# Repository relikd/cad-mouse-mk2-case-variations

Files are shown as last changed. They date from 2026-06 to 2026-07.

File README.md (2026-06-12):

CAD Mouse MK2 - Case Variations
===============================

Based on the 3D files from <https://github.com/sb-ocr/cad-mouse-mk2> (CC-BY-NC-SA-4.0) ... THANK YOU for this project.

The 3D model files in this repo have been recreated from scratch, in [FreeCAD](https://github.com/FreeCAD/FreeCAD/).
The original model sticks to the original step files as closely as possible.

The purpose of this repo is to collect user variations on the original design.

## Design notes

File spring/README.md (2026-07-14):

Spring Designs
==============

All springs come with a default height of 4mm.
If you want a thinner spring, use your slicer to cut down the height (use the scaling feature and click the padlock to scale height independent of width and length).

All designs come with variants for:
- Stem type (`original`/`OG` three screws, `single-center-screw`/`SCS` triangle hole)
- Stem hole orientation (`CF`: flipped for `magnet-holder-v2`, `CN` original orientation `magnet-holder-original`)

See [Tips for experimenting](#tips-for-experimenting) at the end of this readme.

## Spacer

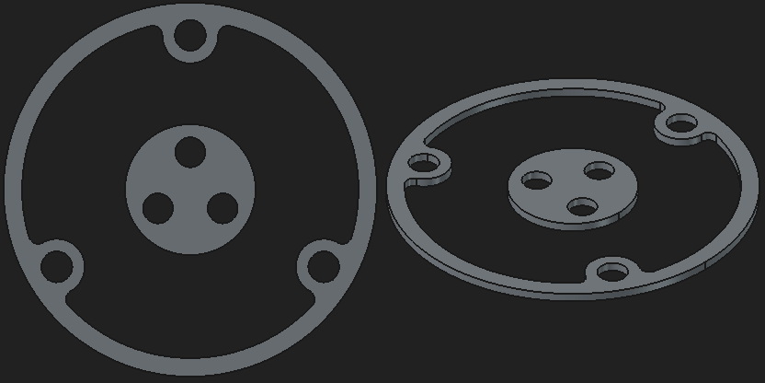
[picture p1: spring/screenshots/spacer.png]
spacer


If you use a thinner spring, you must match the height with a spacer.
`spring` + `spacer` = 4mm.

## Original

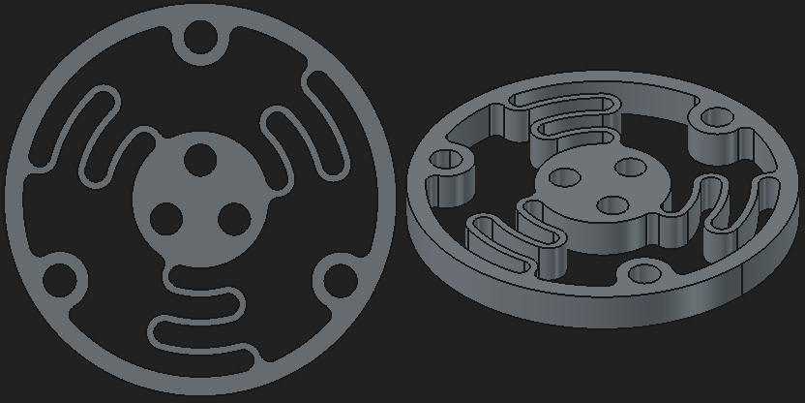
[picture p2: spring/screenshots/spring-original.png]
original


The original spring design by [Salim Benbouziyane](https://github.com/sb-ocr/cad-mouse-mk2).

## Stacked

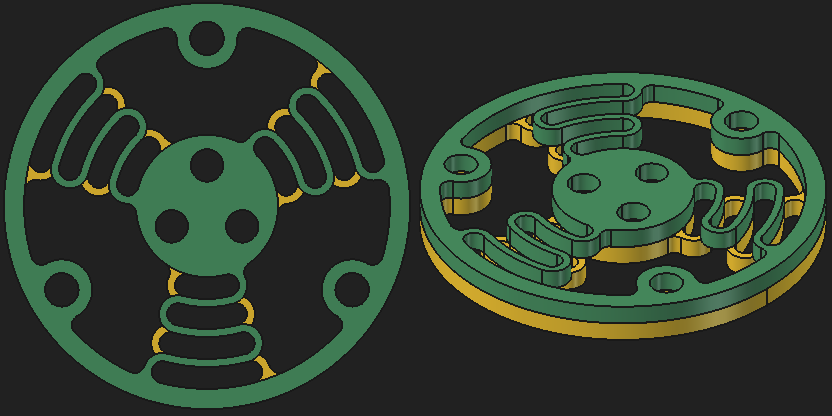
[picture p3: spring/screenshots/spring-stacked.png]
stacked


Print the original spring two times, with half the height (2x 2mm).
Mount them together, such that one side is flipped upside-down.

- Fixes rotation around Z-axis (both directions use the same force)
- Z-axis translation (pull up-/down) is softer (better with a lightweight base)

## Mirrored Double

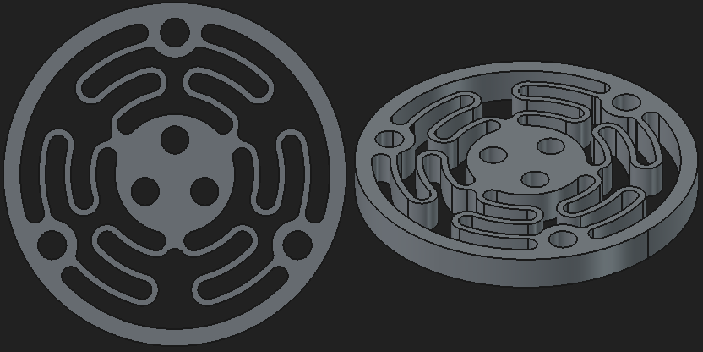
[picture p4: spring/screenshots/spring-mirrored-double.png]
mirrored-double


Same as the `Stacked` variant above but in a single design.
Careful with the height: because this variant uses twice the amount of springs, a 2mm spring will be nearly as stiff as the 4mm `Original` spring.

## Seventeen

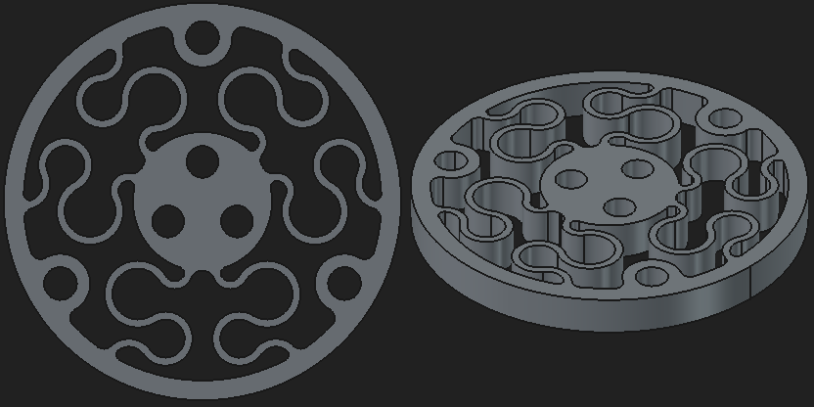
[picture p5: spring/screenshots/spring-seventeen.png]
seventeen


Translation in XY is still not perfect but it strikes a good balance in all DoF.
A height of 2.5mm seems best so far.

The design batch which led to most of the insights in [Tips for experimenting](#tips-for-experimenting).
(large arcs near center, outer ring anchor points at 60° intervals, XY movements, etc.).

See the `attempts/batch-1` folder how miniscule the changes are (v11 - v18).

## Tips for experimenting

- Spring height determines stiffness of the Z-axis.
  For example, with a 2mm spring, the up-/down motion is much easier.
  But on the other hand, tilting also becomes easier.
  E.g., translation on the X- and Y-axis becomes harder because each push may inadvertently rotate the scene.
  It is also a bit harder to rotate around the Z-axis in a steady motion.
- Thinner spring walls increase sensitivity in the X- and Y-axis.
  If you want to go below the 0.8mm in the original design, you'd need a finer nozzle (<0.4mm).
  (unless you are ok with just a single filament line).
- The hardest part, is to find a design which maps 3 springs on a 2-dimensional translation.
  All four XY directions should require the same amount of pressure (or at least: the two opposite directions should require the same force).
  E.g., pulling down on the "bottom" spring should compress equally as the other two springs pushing left- or right.
- If you go for a 6-spring design, try to place the outer-ring anchor points in 60° increments.
  This way, the spring is balanced equally in all four directions.
- Pay attention to spring direction.
  If all springs point in the same direction (like in the original design), rotation around the Z-axis will be easier in one direction than the other.
- The spring is deformed more at the center than at the edges.
  Therefore the center part should be the most flexible (larger arcs).
- When you find a good design, try the extremes.
  Rotate into corners where the spring may collide onto itself or onto the `Knob`.
  Add extra clearance to avoid rasping.
- Always try with the software in a test-scene.
  I had countless spring designs which felt good in a dry run (just the hardware haptics) but did not match my expectations when used in real software.

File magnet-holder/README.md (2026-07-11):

Magnets Holder
==============

## Original

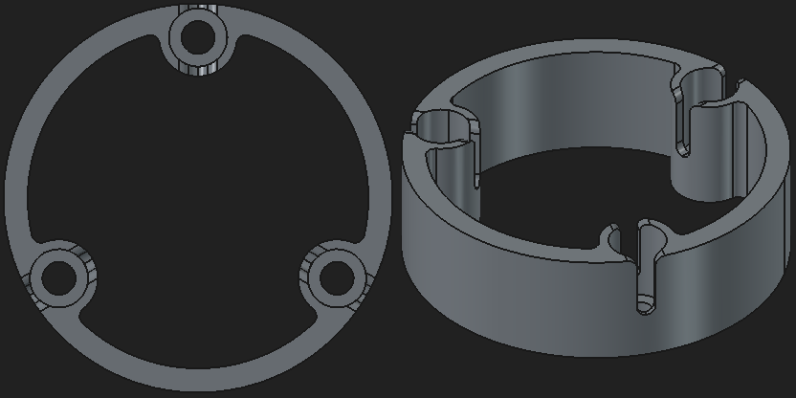
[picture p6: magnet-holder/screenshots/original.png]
original design


=> requires a spring with `_CN_` in name.

## Magnets Holder v2

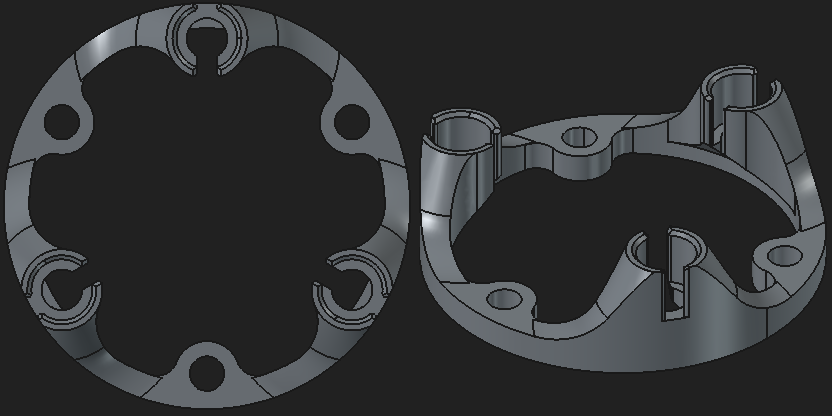
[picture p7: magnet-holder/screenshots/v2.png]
magnets holder v2


=> requires a spring with `_CF_` in name.

Main benefits:
- easier spring changes (unscrew without having to remove the magnets)
- easier magnets dis-/assembly (unscrew first, then handle magnets)
- easy to replace your existing `magnets-holder`

To replace your existing `magnets-holder`, you only need a new `spring`.
In the original spring, the center holes are pointing in the same direction as the holes on the outside ring.
For this `magnets-holder-v2`, they need to point in the opposite direction:

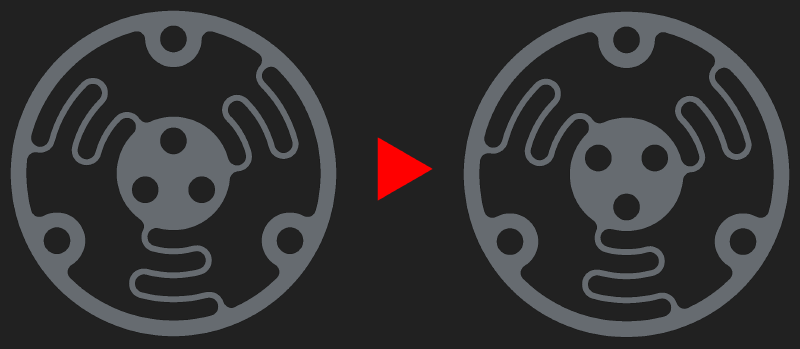
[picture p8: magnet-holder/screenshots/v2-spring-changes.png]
spring changes for v2


__Note:__ The magnets require a press-fit.
If they fall out, adjust the magnets-diameter variable.

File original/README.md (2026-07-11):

License: CC-BY-NC-SA 4.0

The FreeCAD and STL files in this folder were created by relikd.

The files in the STEP folder were extracted - without modification - from the original design.

Original design by [Salim Benbouziyane](https://github.com/sb-ocr/cad-mouse-mk2).

### Improvements

- fix counterbore overhangs with bridging (`Bottom Shell`, `Bottom Lid`).
- replace overhang fillets (z-axis) with 45° chamfers (`Knob`, `Bottom Shell`, `Bottom Lid`, `Button`).

#### Additional parts

- `magnet-holder`
- `spring`

### Notes

`base-shell-top` is the only part which needs supports.
For aesthetic reasons, the part should be printed in the final orientation such that it has a smooth top curvature.
You *could* print it upside-down (without support) but that will create a hard edge on the top (visible part).

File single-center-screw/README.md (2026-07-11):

Author: relikd

Based on: `original` + `print-improvements`

---

Re-designed to assemble all parts with a single center screw (M5) while maximizing bottom volume for weights.

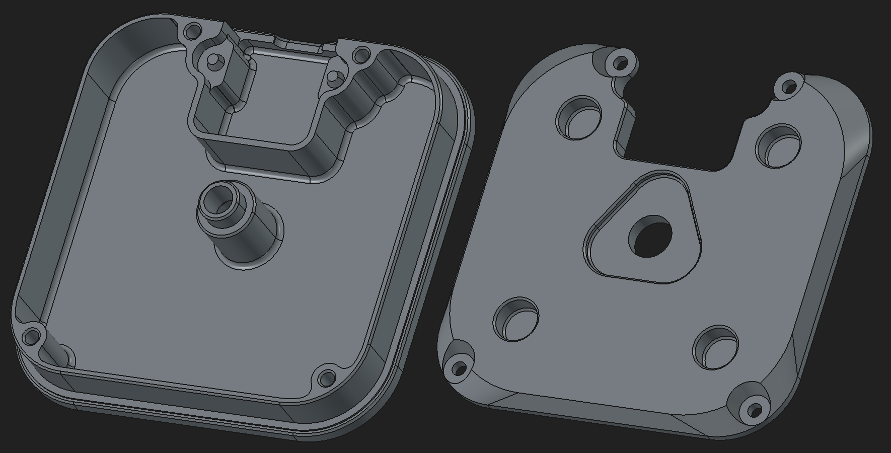
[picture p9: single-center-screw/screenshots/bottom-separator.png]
bottom and separator

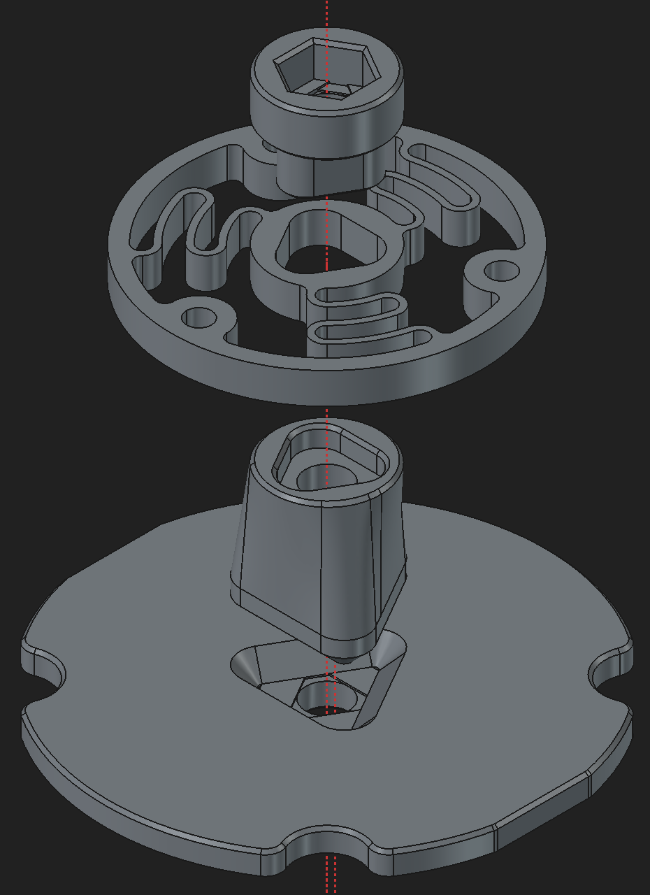
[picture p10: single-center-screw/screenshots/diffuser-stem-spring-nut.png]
stacked parts: diffuser, stem, spring, nut-cage


### Changes

- All heights are calculated from sensors board + MCU dimensions.
  This assures a minimal possible height and allows customizations for custom PCB designs.
- The `Top` and `Bottom` are fixed with self-tapping screws (no heat-set inserts needed, just regular 3mm).
- The model files `Top`, `Button`, and `Diffuser` have variant options (screw type and PCB variants (see below).
  All models have `VarSet` variables.

#### PCB variants

- Original (PCB design by [sb-ocr](https://github.com/sb-ocr/cad-mouse-mk2), the original release)
- Nikki (PCB design by [sheffieldnikki](https://github.com/sb-ocr/cad-mouse-mk2/issues/24), community variant, mounting the MCU directly onto the sensors board)

#### Additional parts

- `Knob` (from `original`)
- `magnet-holder`
- `spring`

### Print settings

- The model is tweaked for a minimum layer height of 0.2mm.
  Try not to go above or else you will have overhangs in screw holes etc. (or: adjust the printer variables in the model files)
- Only `Top` needs supports.
  All other parts have bridges for overhangs and should print without supports.

### Steel plate weight

Use `template-bottom-weight.dxf`, if you want to cut the weights from a steel plate.
The maximum possible height is 12.2mm - you can cut 3x 4mm plates or 2x 5mm.

### Bill of materials

I've included a range of possible screw lengths, just so you can re-use some scrap screws laying around.

- 6x Magnets 6mm x 3mm (same as original)
- 1x M5 x 40, Hexagon Socket Head Cap Screw
- 1x M5 nut
- 3x M3 x 10-12mm (`Knob`)
- 3x M3 Heat-Set Inserts 4mm (`Knob`)
- 4x M3 x 5-12mm (or Self-Tapping screws), sink head or another flat head with a low profile (<2mm)
  (connects `Separator` to `Bottom` and *may* collide with `Top` if head sticks out too much)
- 4x M3 x 4-7mm  (or Self-Tapping screws), any flat head type will do (connects PCB to `Top`)

Self-tapping screws are fine, because you won't need to open these parts very often (if ever).
Even if you do, a few screwing - unscrewing cycles should be fine.

Instead of self-tapping screws, you can use M3 screws *without* heat-set inserts, they will hold fine as well.
I still recommend heat-set inserts for the `Knob` as you might need to replace the `Spring` regularly.

If you use heat-sets for the top, you should adapt your hole size variable (e.g., 4.4mm).

### Assembly

The mouse consists of three main parts: bottom, top, and knob.

1. Fill the `Bottom` with weights (e.g., steel balls), fill it up with wax and then close it off with the `Separator`.
2. Place the `Diffuser` in the `Top` shell (the diffuser cut-out should point in the same direction as the USB port).
   Place the PCB onto the diffuser (pinout in the same direction).
   Then, screw both together and insert the MCU.
3. Combine the `Stem`, `Spring`, and `Nut-Cage`.
   Place the M5 nut into the cage.
   Combine this stack with the `Magnet-Holder` and fix both into the `Knob`.
4. Finally, stack all three components loosely together and insert the M5 screw carefully.
   Don't push too hard, or the nut will fall out (and you'll have to disassamble the knob again).

The single M5 screw holds all parts together.
Most parts have a tight fit.
Especially the spring and stem should fit as perfect as possible (reduces rotational wobble).

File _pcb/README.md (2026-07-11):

PCB variants
============

- `original` PCB files for <https://github.com/sb-ocr/cad-mouse-mk2>
- `nikki` PCB variant by [sheffieldnikki](https://github.com/sheffieldnikki).
See <https://github.com/sb-ocr/cad-mouse-mk2/issues/24>

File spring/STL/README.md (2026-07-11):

`{VARIANT}_{FLIPPED}_{filename}.stl`

VARIANT:
- OG: `Original` (three center holes)
- SCS: `Single-Center-Screw` (triangle center hole)

FLIPPED:
- CN: `non-flipped` (original orientation. Center holes point to magnets. `magnet-holder-original`)
- CF: `flipped` (center hole upside-down. Holes point between magnets. `magnet-holder-v2`)

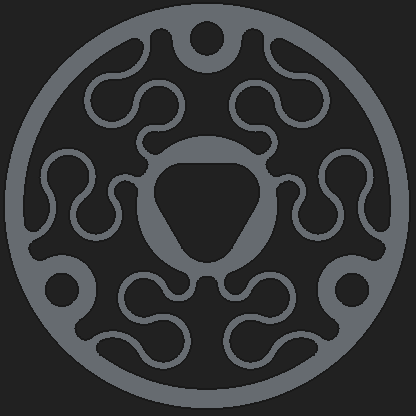
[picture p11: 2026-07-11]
spring/attempts/batch-1/v13.png

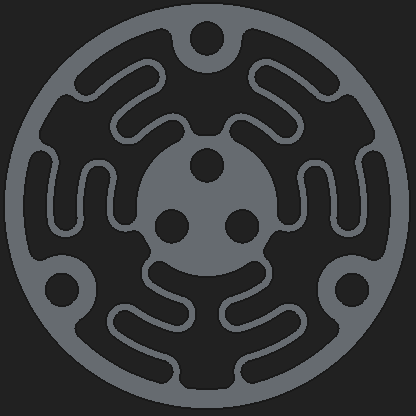
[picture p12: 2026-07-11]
spring/attempts/batch-1/v2.png

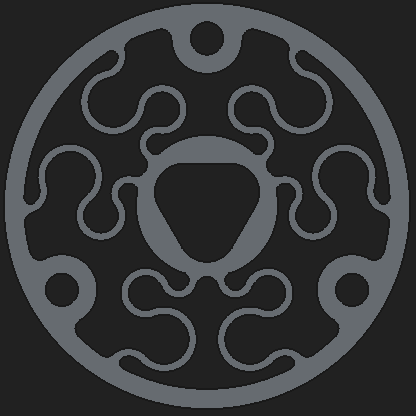
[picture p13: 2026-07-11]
spring/attempts/batch-1/v18.png

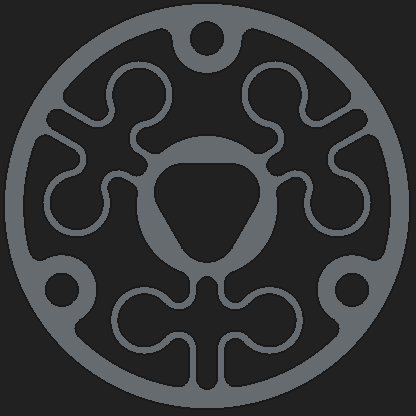
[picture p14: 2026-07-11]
spring/attempts/batch-1/v10.png

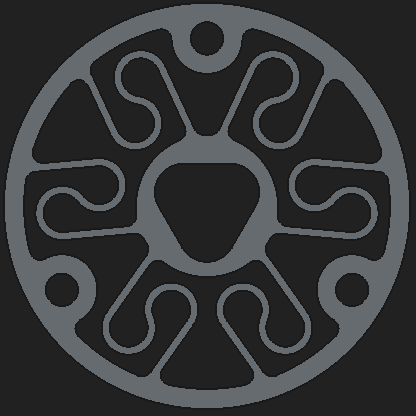
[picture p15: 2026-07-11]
spring/attempts/batch-1/v7.png

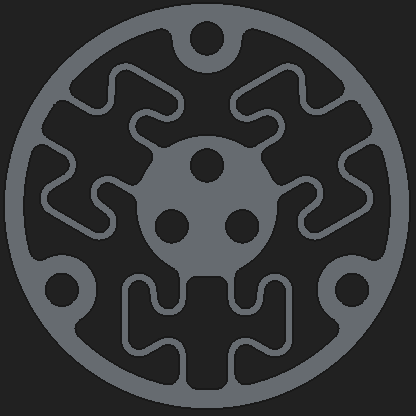
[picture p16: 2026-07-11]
spring/attempts/batch-1/v9.png

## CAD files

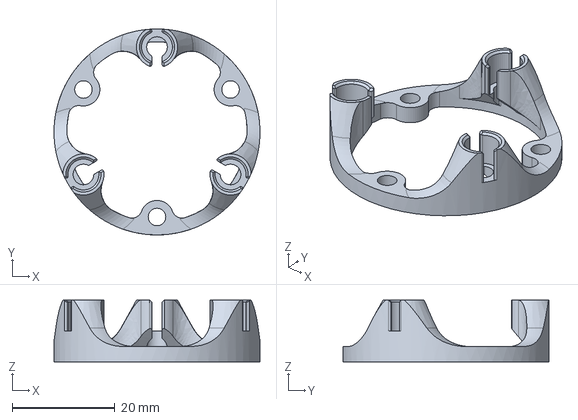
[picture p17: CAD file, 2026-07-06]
magnet-holder/magnet-holder-v2.FCStd
40.0 x 40.0 x 12.0 mm

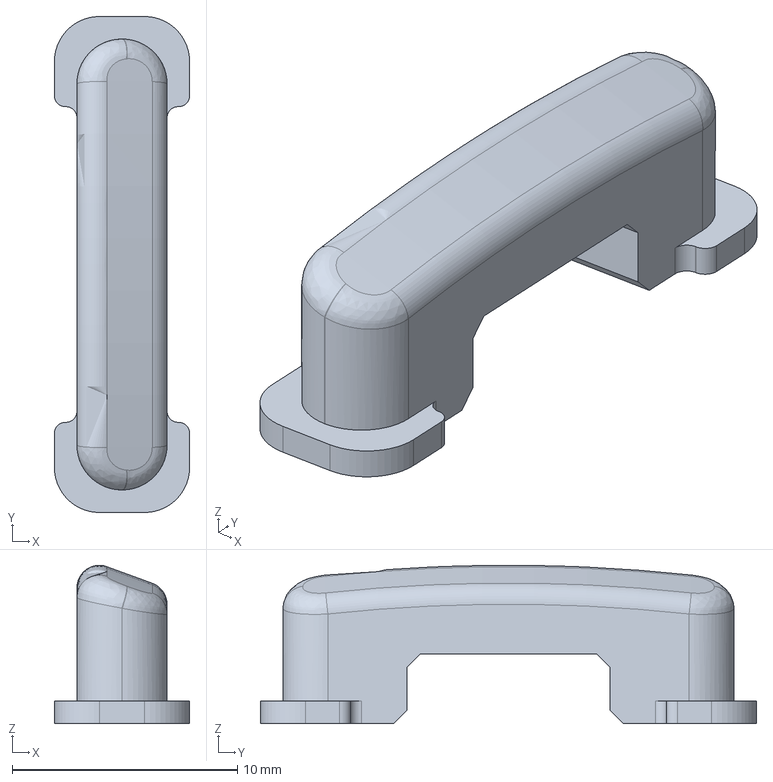
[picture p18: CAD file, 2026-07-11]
original/button.FCStd
6.00 x 22.0 x 7.03 mm

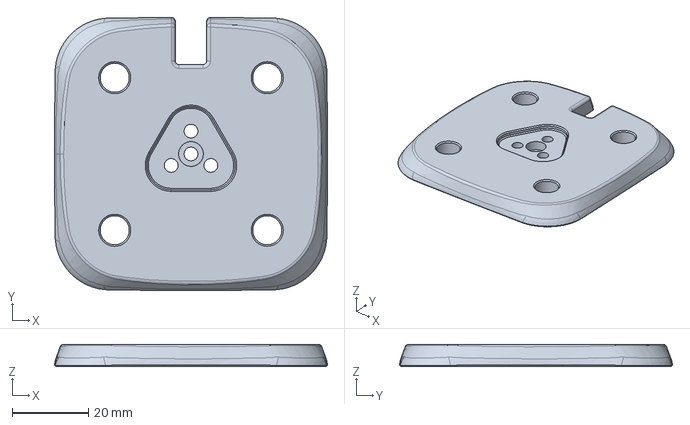
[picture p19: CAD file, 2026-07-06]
original/STEP/Base _Bottom Sep.step
71.6 x 71.6 x 5.90 mm

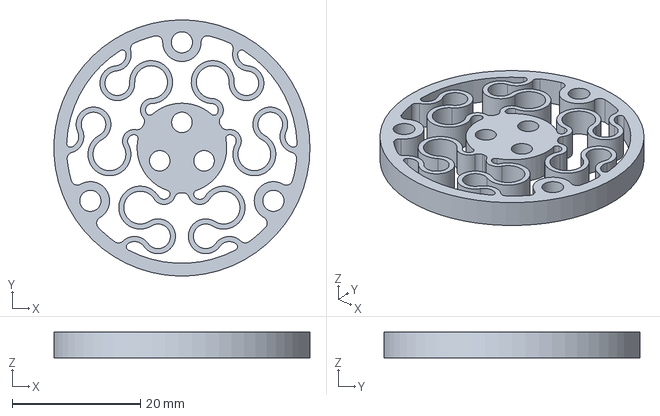
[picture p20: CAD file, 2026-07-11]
spring/spring-seventeen.FCStd
40.0 x 40.0 x 4.00 mm

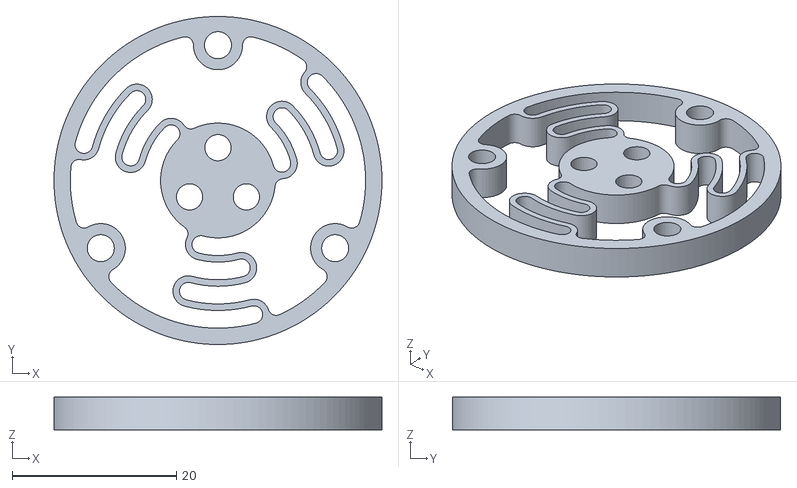
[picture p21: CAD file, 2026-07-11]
spring/STL/OG_CN_spring-original.stl
40.0 x 40.0 x 4.00

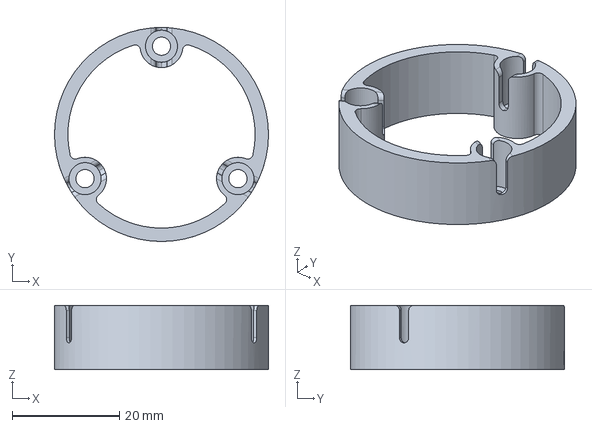
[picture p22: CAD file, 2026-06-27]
magnet-holder/magnet-holder-original.FCStd
40.0 x 40.0 x 12.0 mm

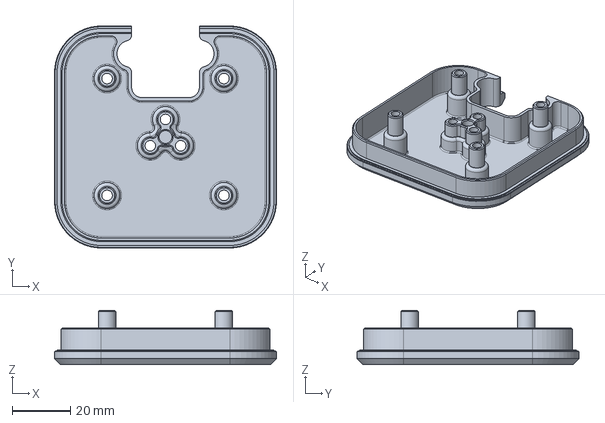
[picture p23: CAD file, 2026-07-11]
original/base-shell-bottom.FCStd
76.0 x 76.0 x 18.5 mm

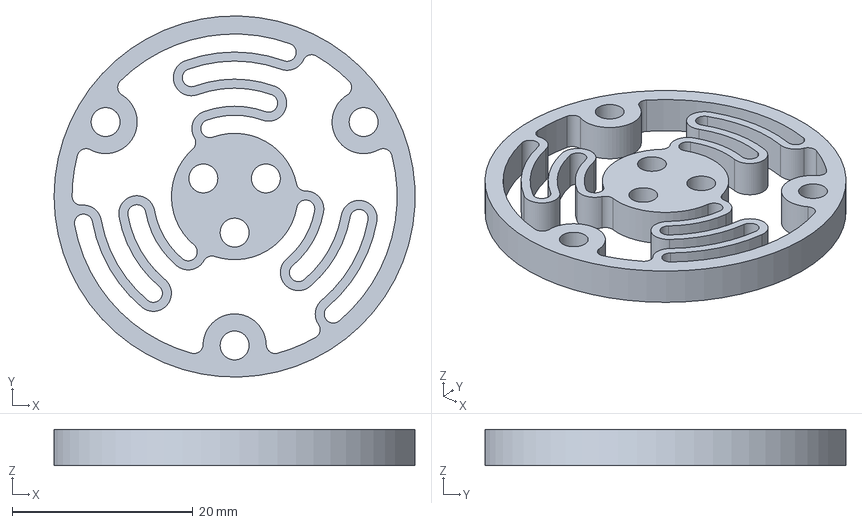
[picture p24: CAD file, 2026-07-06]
original/STEP/Spring v6.step
40.0 x 40.0 x 4.00 mm

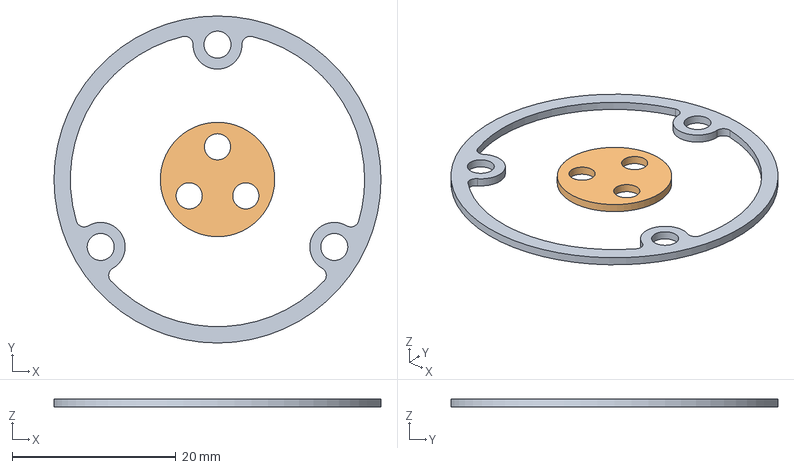
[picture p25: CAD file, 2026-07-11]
spring/spacer.FCStd
40.0 x 40.0 x 1.00 mm
Ring
Center

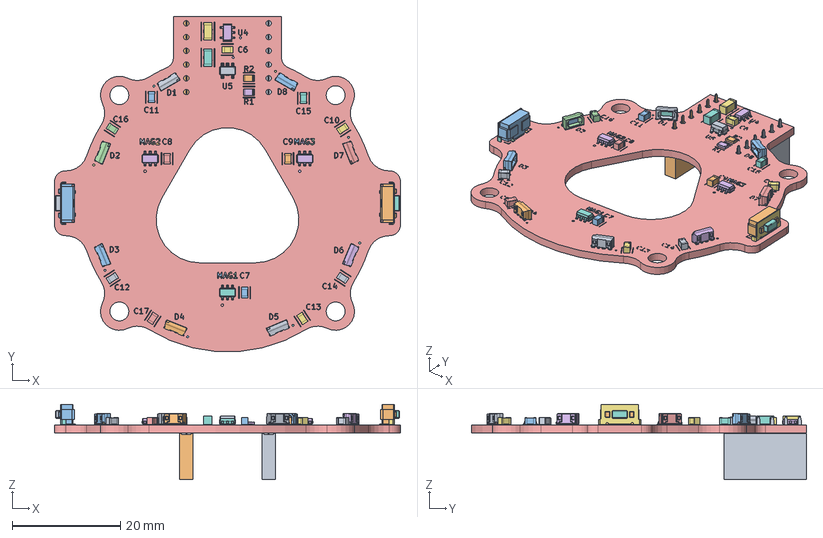
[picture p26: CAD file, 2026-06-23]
_pcb/nikki-sensorboard.FCStd
64.0 x 62.0 x 13.9 mm
SOT-23-5
SK6812 SIDE-A--3DModel-STEP-269445
SK6812 SIDE-A--3DModel-STEP-269446
SK6812 SIDE-A--3DModel-STEP-269447
SK6812 SIDE-A--3DModel-STEP-269448
SK6812 SIDE-A--3DModel-STEP-269449
SK6812 SIDE-A--3DModel-STEP-269450
SK6812 SIDE-A--3DModel-STEP-269452
SK6812 SIDE-A--3DModel-STEP-269453
SK6812 SIDE-A--3DModel-STEP-269454
SK6812 SIDE-A--3DModel-STEP-269455
SK6812 SIDE-A--3DModel-STEP-269456
SK6812 SIDE-A--3DModel-STEP-269457
TSOP-6_1.65x3.05mm_P0.95mm
C_0805_2012Metric
TS32-7-35-BK-B-160-RA-SMT-TR
TS32-7-35-BK-B-160-RA-SMT-TR001
TS32-7-35-BK-B-160-RA-SMT-TR002
TS32-7-35-BK-B-160-RA-SMT-TR003
TS32-7-35-BK-B-160-RA-SMT-TR004
SK6812 SIDE-A--3DModel-STEP-269459
SK6812 SIDE-A--3DModel-STEP-269460
SK6812 SIDE-A--3DModel-STEP-269461
SK6812 SIDE-A--3DModel-STEP-269462
SK6812 SIDE-A--3DModel-STEP-269463
SK6812 SIDE-A--3DModel-STEP-269464
SK6812 SIDE-A--3DModel-STEP-269466
SK6812 SIDE-A--3DModel-STEP-269467
SK6812 SIDE-A--3DModel-STEP-269468
SK6812 SIDE-A--3DModel-STEP-269469
SK6812 SIDE-A--3DModel-STEP-269470
SK6812 SIDE-A--3DModel-STEP-269471
C_0805_2012Metric001
R_0805_2012Metric
C_0805_2012Metric002
SK6812 SIDE-A--3DModel-STEP-269473
SK6812 SIDE-A--3DModel-STEP-269474
SK6812 SIDE-A--3DModel-STEP-269475
SK6812 SIDE-A--3DModel-STEP-269476
SK6812 SIDE-A--3DModel-STEP-269477
SK6812 SIDE-A--3DModel-STEP-269478
SK6812 SIDE-A--3DModel-STEP-269480
SK6812 SIDE-A--3DModel-STEP-269481
SK6812 SIDE-A--3DModel-STEP-269482
SK6812 SIDE-A--3DModel-STEP-269483
SK6812 SIDE-A--3DModel-STEP-269484
SK6812 SIDE-A--3DModel-STEP-269485
SK6812 SIDE-A--3DModel-STEP-269487
SK6812 SIDE-A--3DModel-STEP-269488
SK6812 SIDE-A--3DModel-STEP-269489
SK6812 SIDE-A--3DModel-STEP-269490
SK6812 SIDE-A--3DModel-STEP-269491
SK6812 SIDE-A--3DModel-STEP-269492
TSOP-6_1.65x3.05mm_P0.95mm001
TS32-7-35-BK-B-160-RA-SMT-TR006
TS32-7-35-BK-B-160-RA-SMT-TR007
TS32-7-35-BK-B-160-RA-SMT-TR008
TS32-7-35-BK-B-160-RA-SMT-TR009
TS32-7-35-BK-B-160-RA-SMT-TR010
C_0805_2012Metric003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

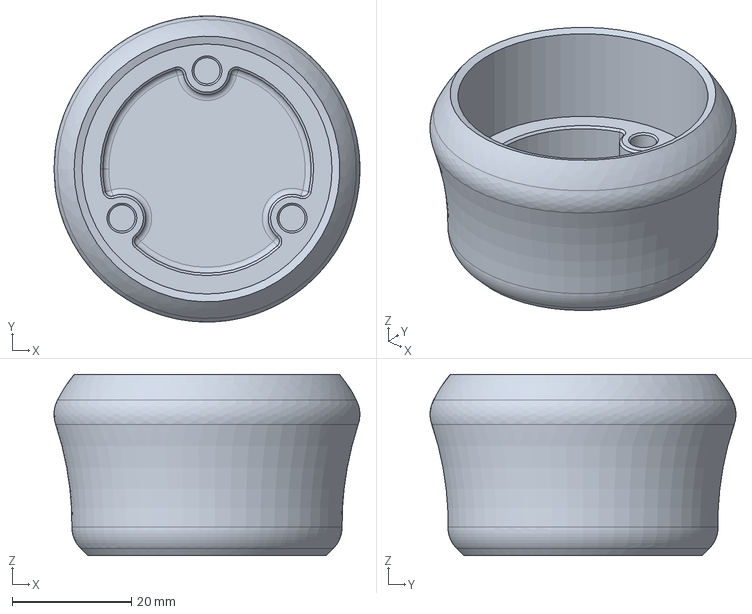
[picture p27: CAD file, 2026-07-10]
original/knob.FCStd
51.4 x 51.4 x 30.5 mm

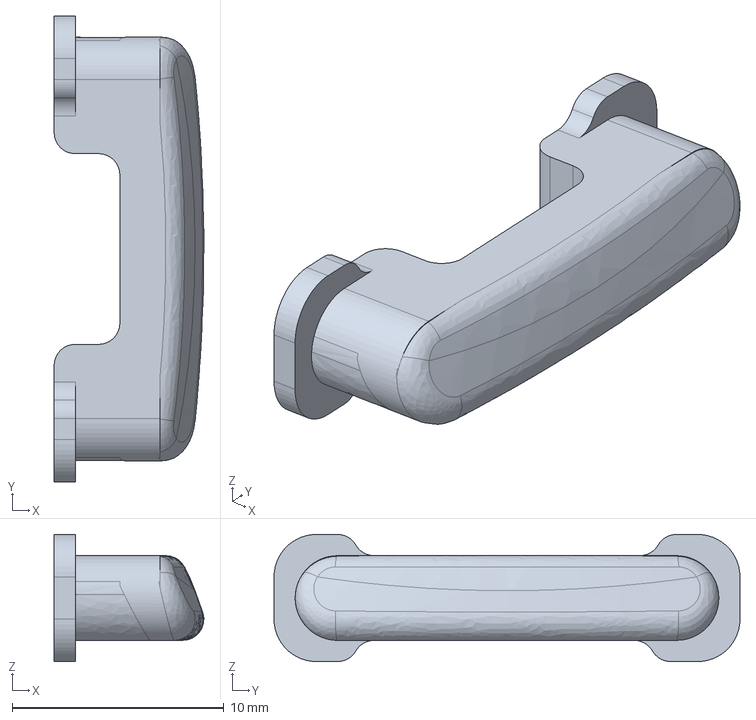
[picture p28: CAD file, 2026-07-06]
original/STEP/Buttons.step
7.07 x 22.0 x 6.00 mm

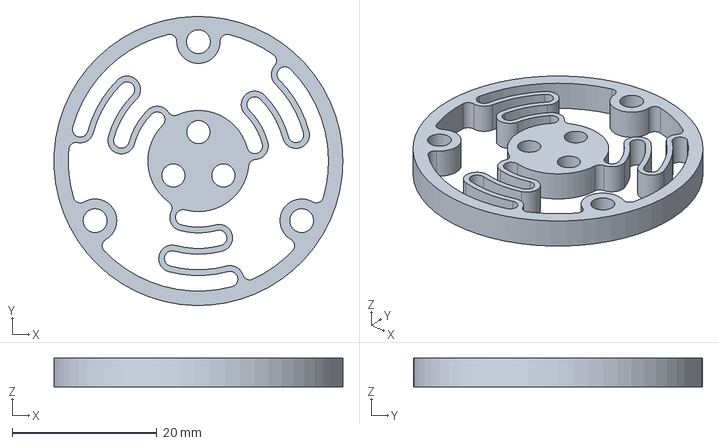
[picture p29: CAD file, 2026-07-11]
spring/spring-original.FCStd
40.0 x 40.0 x 4.00 mm

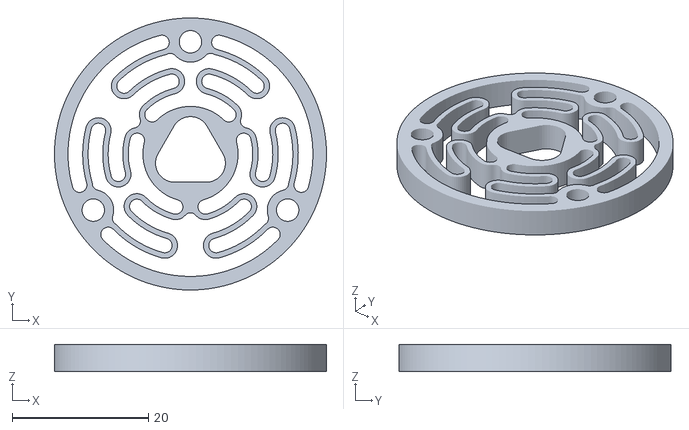
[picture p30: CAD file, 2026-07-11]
spring/STL/SCS_CN_spring-mirrored-double.stl
40.0 x 40.0 x 4.00

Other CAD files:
_pcb/original-assembly.FCStd
_pcb/nikki-assembly.FCStd
spring/STL/OG_CN_spacer.stl
_pcb/nikki-mcu.FCStd
_pcb/original-mcu.FCStd
_pcb/original-sensorboard.FCStd
magnet-holder/STL/magnet-holder-original.stl
magnet-holder/STL/magnet-holder-v2.stl
original/STEP/Base _Bottom Lid.step
original/STEP/Base _Bottom.step
original/STEP/Base _Top.step
original/STEP/Diffuser.step
original/STEP/Knob v11.step
original/STEP/Magnets Holder v11.step
original/STEP/Spring Spacer v4.step
original/STEP/Stem v9.step
original/STL/base-bottom-lid.stl
original/STL/base-separator.stl
original/STL/base-shell-bottom.stl
original/STL/base-shell-top.stl
original/STL/button.stl
original/STL/diffuser.stl
original/STL/knob.stl
original/STL/spring-spacer.stl
original/STL/stem.stl
original/base-bottom-lid.FCStd
original/base-separator.FCStd
original/base-shell-top.FCStd
original/diffuser.FCStd
original/spring-spacer.FCStd
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

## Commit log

2026-06-13 fix: assembly references + exploded view
    [assembly.FCStd]
2026-06-13 feat: add print-improvements
    [base-bottom-lid.FCStd, base-shell-bottom.FCStd, button.FCStd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]
2026-06-14 feat: stls + remove notch from knob + larger notch
    [base-bottom-lid.FCStd, base-bottom-lid.stl, base-shell-bottom.FCStd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]
2026-06-23 feat: STL for original
    [base-bottom-lid.stl, base-separator.stl, base-shell-bottom.stl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]
2026-06-23 ref: move PCBs into separate folder
    [assembly.FCStd, mcu.FCStd, sensorboard.FCStd]
2026-06-23 chore: move stl into STL folder
    [base-bottom-lid.stl, base-shell-bottom.stl, button.stl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]
2026-06-23 feat: pcb-nikki
    [assembly.FCStd, mcu.FCStd, sensorboard.FCStd]
2026-06-23 fix: heat-set inserts hole size 4.2mm
    [knob.FCStd, knob.stl]
2026-06-26 feat: single-center-screw
    [all.FCStd, bottom.FCStd, bottom.stl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]
2026-06-27 ref: make head-height an option variable
    [magnet-holder.FCStd]
2026-06-27 fix: hole size of separator independent of bottom
    [bottom.FCStd, separator.stl]
2026-06-27 ref: edit hole size variable directly without checkbox
    [top.FCStd]
2026-06-27 chore: update readme for single-center-screw
2026-06-29 feat: spring-mirrored-double
    [spring-double.FCStd]
2026-06-29 chore: stl files for spring-mirrored-double
    [spacer-original-0.5mm.stl, spacer-original-1.0mm.stl, spacer-original-1.5mm.stl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]
2026-07-03 feat: steel plate weight
    [bottom.FCStd, template-bottom-weight.dxf]
2026-07-05 fix: chamfer on button + fix STL artifacts
    [button-nikki.stl, button-original.stl, button.FCStd]
2026-07-05 fix: button placement (wrong calculation)
    [top-nikki-with-heatset.stl, top-nikki-without-heatset.stl, top-original-with-heatset.stl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]
2026-07-06 feat: original step files separated
    [Base _Bottom Lid.step, Base _Bottom Sep.step, Base _Bottom.step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]
2026-07-06 feat: magnets holder v2
    [magnet-holder-v2.FCStd, magnet-holder-v2.stl, spring-double.FCStd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]
2026-07-10 fix: button rim distance + remove top inner fillet
    [spring-2mm.stl, spring.stl, top-nikki-with-heatset.stl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]
2026-07-10 fix: heat-set insert hole size 4.4mm
    [knob.FCStd, knob.stl]
2026-07-11 ref: consolidate all springs into single folder
    [OG_CF_spacer.stl, OG_CF_spring-mirrored-double.stl, OG_CF_spring-original.stl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]
2026-07-11 feat: spring v17
    [OG_CF_spring-seventeen.stl, OG_CN_spring-seventeen.stl, SCS_CF_spring-seventeen.stl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]
2026-07-11 chore: rm export script, creates too large files
    [OG_CF_spacer.stl, OG_CF_spring-mirrored-double.stl, OG_CF_spring-original.stl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]
2026-07-11 ref: merge print improvements into original design
    [base-bottom-lid.FCStd, base-bottom-lid.stl, base-shell-bottom.FCStd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]
2026-07-11 chore: rm assembly, always breaks on edits
    [all.FCStd, assembly.FCStd, top-button.FCStd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]
2026-07-11 chore: consolidate PCB designs into single folder
    [assembly.FCStd, nikki-assembly.FCStd, nikki-mcu.FCStd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]
2026-07-11 ref: consolidate magnet-holder into separate dir
    [magnet-holder-original.FCStd, magnet-holder-original.stl, magnet-holder-v2.FCStd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]
2026-07-11 doc: height range for spring v17
2026-07-14 fix: reduce distance between buttons
    [top-nikki.stl, top-original.stl, top.FCStd]
2026-07-14 doc: spring height of 2.5mm is best
